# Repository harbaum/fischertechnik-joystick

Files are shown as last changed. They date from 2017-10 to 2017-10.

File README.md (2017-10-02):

# fischertechnik-joystick

This is a simple joystick interface for fischertechnik. It connects
to any PC and has ft compatible IOs for 8 fire buttons, four digital
direction buttons and four analog axes.

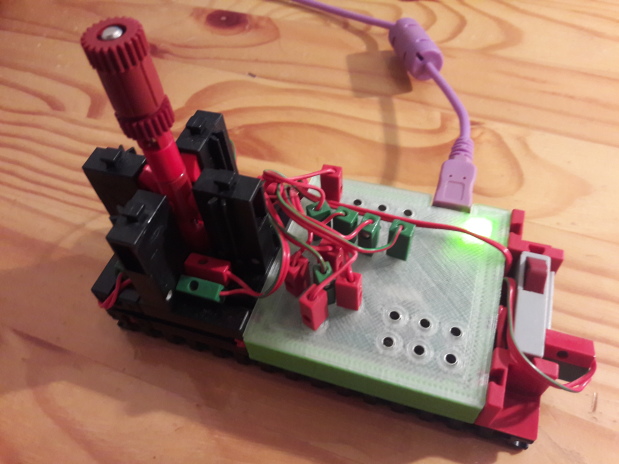
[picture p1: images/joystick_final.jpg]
 

This repository contains the schematic and the board layout in eagle format,
the firmware source code and a 3D printable case design.



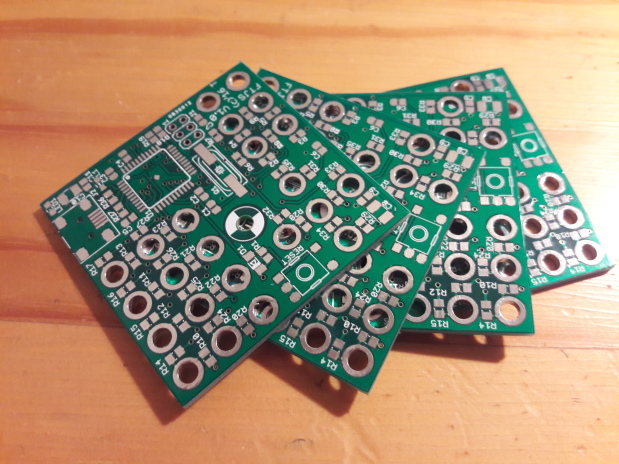
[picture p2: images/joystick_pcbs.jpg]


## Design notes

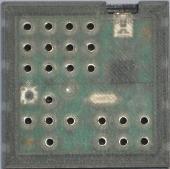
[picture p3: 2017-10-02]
images/prototype.jpg

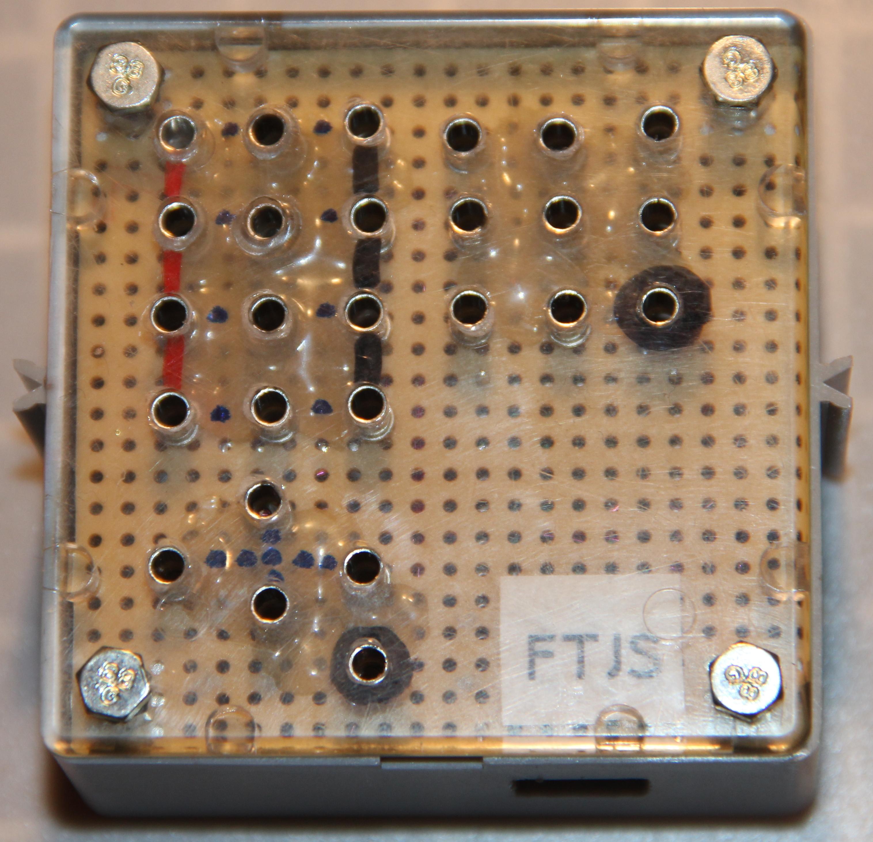
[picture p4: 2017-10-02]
images/modul.JPG

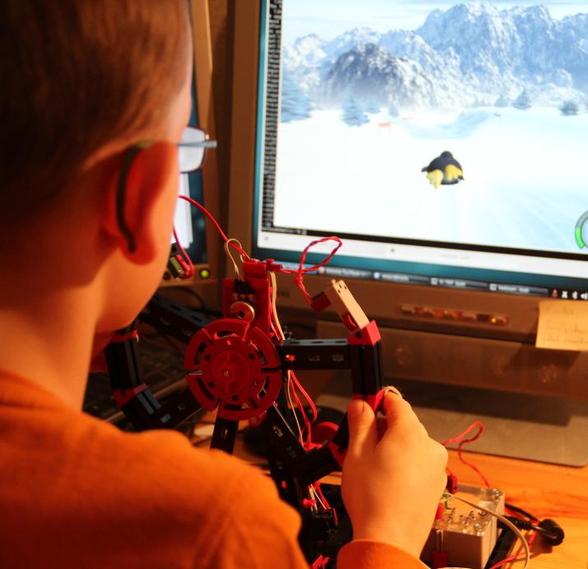
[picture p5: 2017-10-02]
images/ft_js.jpg

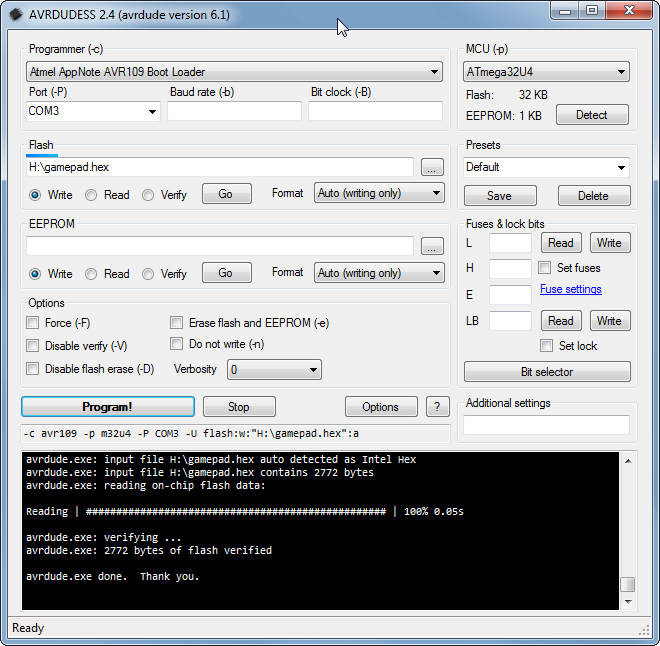
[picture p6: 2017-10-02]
images/avrdudess.png

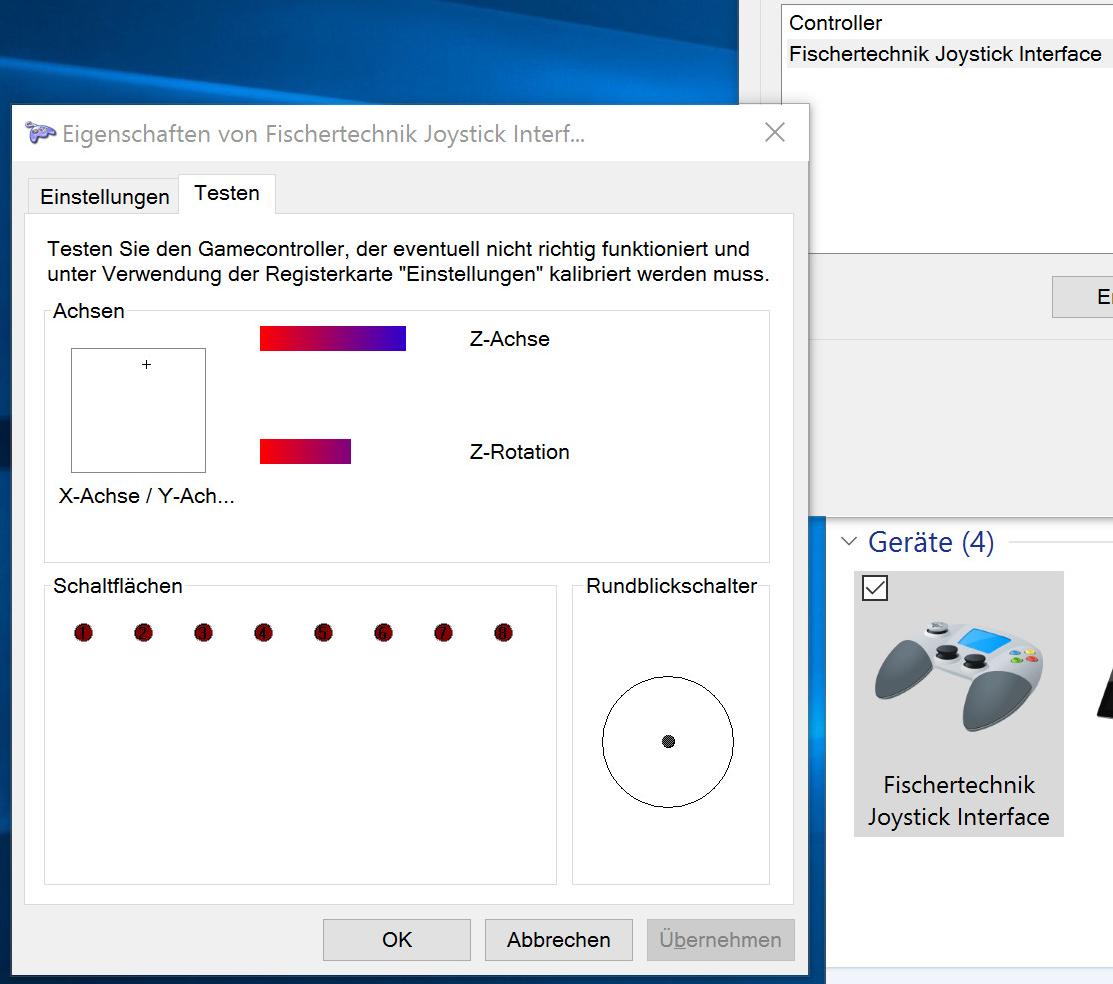
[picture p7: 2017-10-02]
images/win.jpg

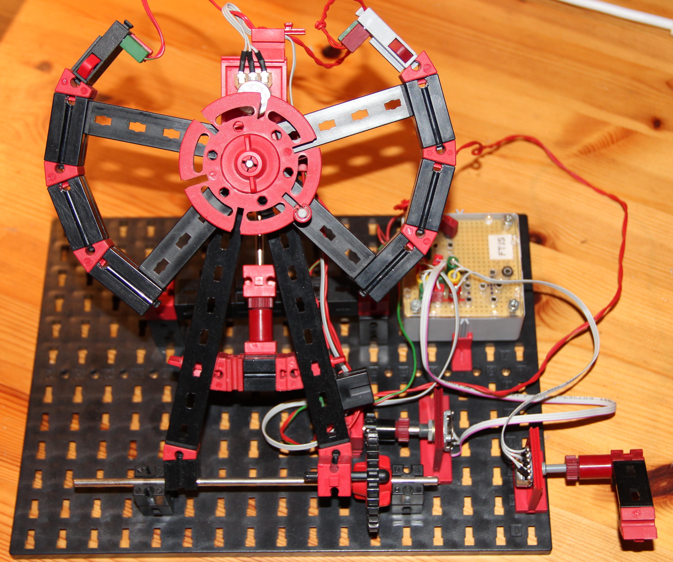
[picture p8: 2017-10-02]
images/lenkrad.JPG

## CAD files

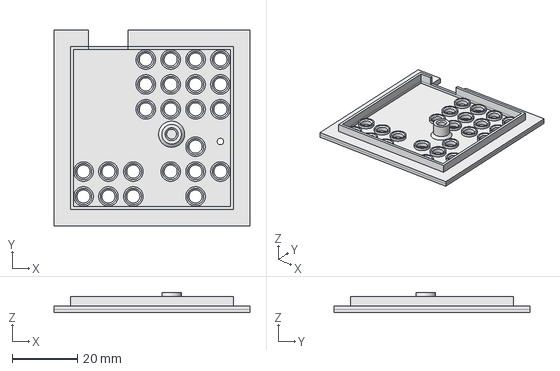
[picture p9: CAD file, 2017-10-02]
case/top.fcstd
60.0 x 60.0 x 6.20 mm

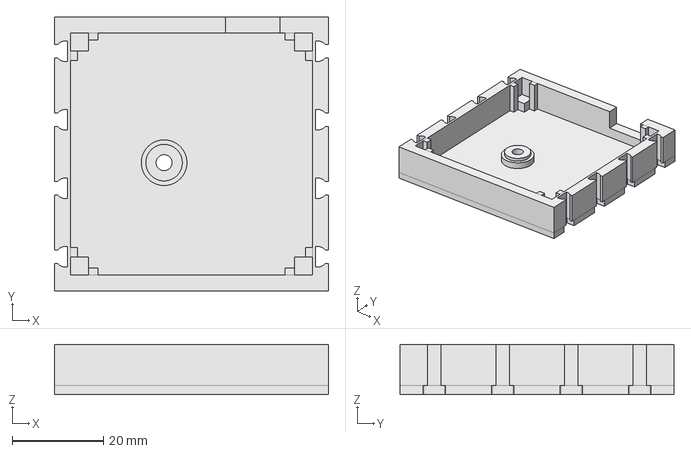
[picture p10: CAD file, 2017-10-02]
case/bottom.fcstd
60.0 x 60.0 x 11.0 mm

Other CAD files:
case/bottom.stl
case/top.stl

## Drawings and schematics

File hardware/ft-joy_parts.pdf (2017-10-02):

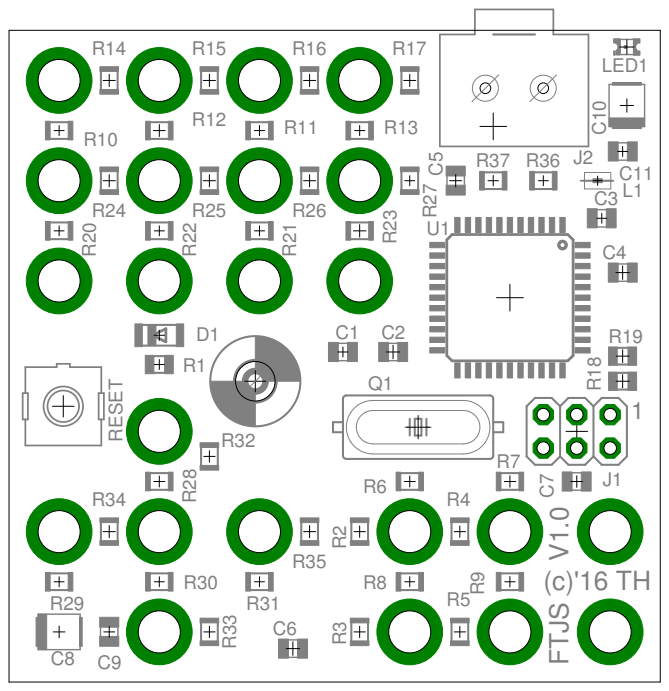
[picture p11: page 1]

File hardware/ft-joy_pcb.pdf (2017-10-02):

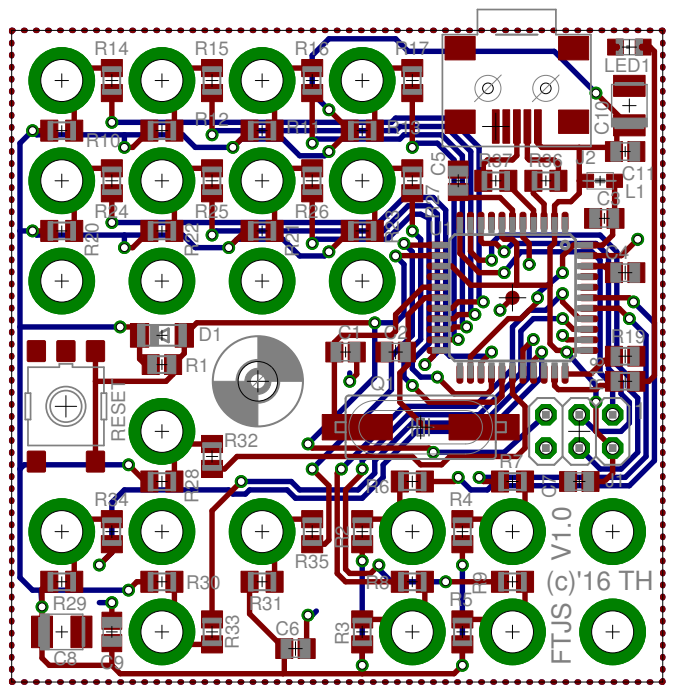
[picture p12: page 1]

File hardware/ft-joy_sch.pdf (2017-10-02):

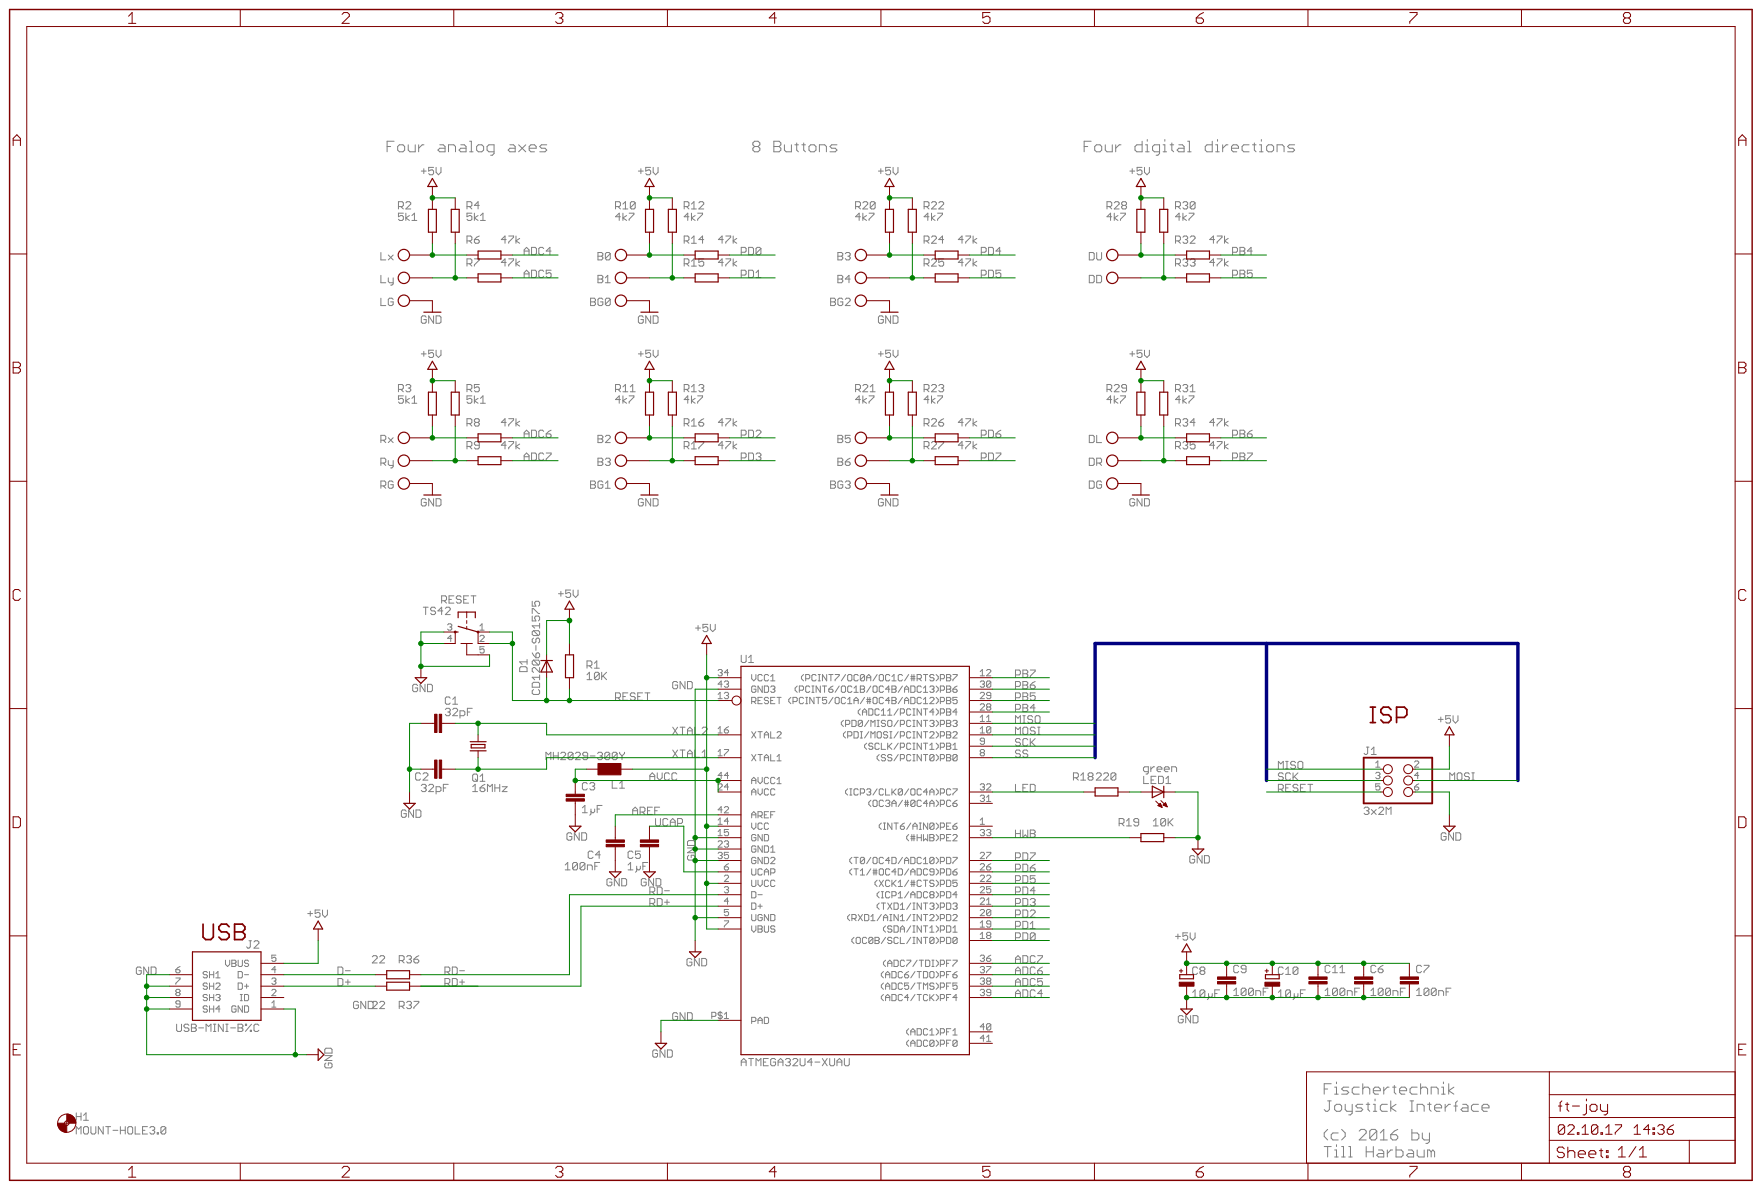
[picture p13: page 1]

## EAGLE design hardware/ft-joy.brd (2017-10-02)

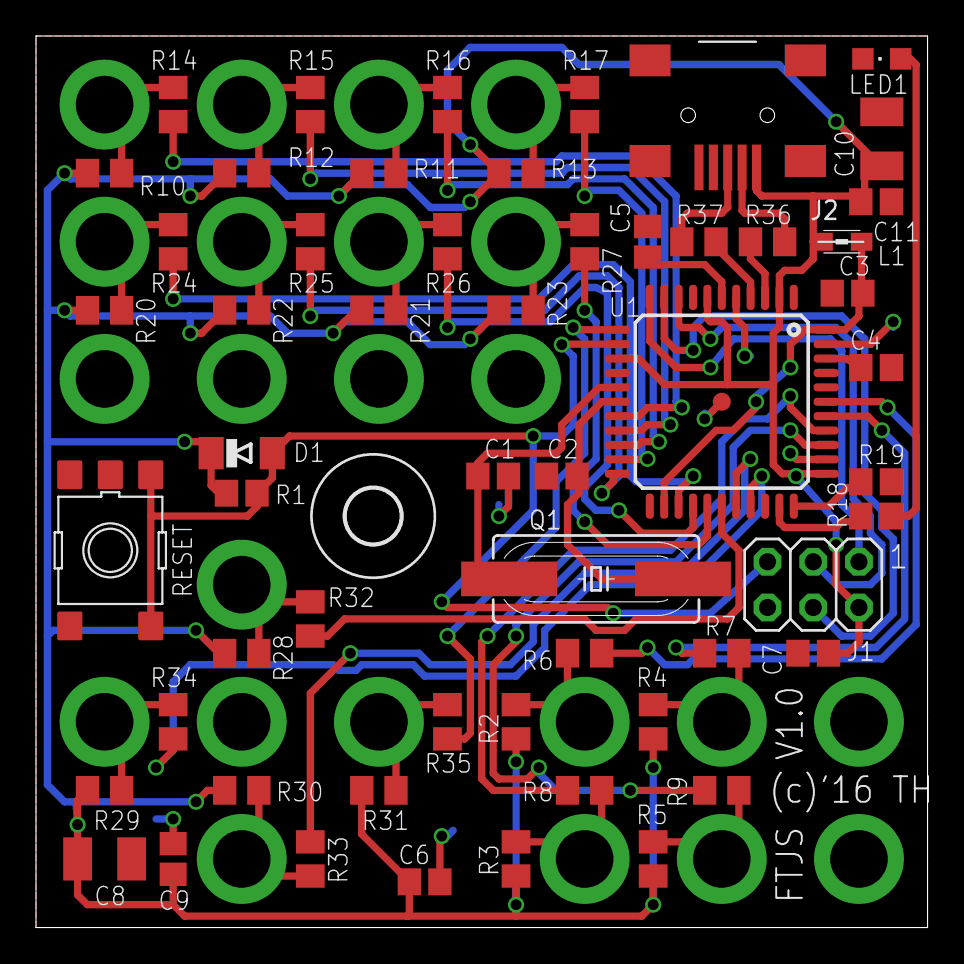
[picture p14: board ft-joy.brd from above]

Board: 2 copper layers, 49.5 x 49.5 mm, 80 parts (0 on the bottom side), 50 nets.

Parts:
C1, C2: 32pF; C0805
C3, C5: 1µF; C0805
C4, C6, C7, C9, C11: 100nF; C0805
C8, C10: 10µF; SMC_B
D1: CD1206-S01575; MINIMELF
H1: MOUNT-HOLE3.0; 3,0
J1: 3x2M; 2X03
J2: USB-MINI-B%C; USB-MINI-B_2
L1: MH2029-300Y; 0805
LED1: green; CHIPLED_0805
P1: Lx; FT-HUELSE
P2: Ly; FT-HUELSE
P3: LG; FT-HUELSE
P4: Rx; FT-HUELSE
P5: Ry; FT-HUELSE
P6: RG; FT-HUELSE
P7: B0; FT-HUELSE
P8: B1; FT-HUELSE
P9: BG0; FT-HUELSE
P10: B2; FT-HUELSE
P11, P13: B3; FT-HUELSE
P12: BG1; FT-HUELSE
P14: B4; FT-HUELSE
P15: BG2; FT-HUELSE
P16: B5; FT-HUELSE
P17: B6; FT-HUELSE
P18: BG3; FT-HUELSE
P19: DU; FT-HUELSE
P20: DD; FT-HUELSE
P21: DL; FT-HUELSE
P22: DR; FT-HUELSE
P23: DG; FT-HUELSE
Q1: 16MHz; HC49UP
R1, R19: 10K; R0805
R2, R3, R4, R5: 5k1; M0805
R6, R7, R8, R9, R14, R15, R16, R17, R24, R25, R26, R27, R32, R33, R34, R35: 47k; M0805
R10, R11, R12, R13, R20, R21, R22, R23, R28, R29, R30, R31: 4k7; M0805
R18: 220; R0805
R36, R37: 22; M0805
RESET: TS42
U1: ATMEGA32U4-XUAU; TQFP44-PAD

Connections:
+5V: C6.1, C7.1, C8.+, C9.1, C10.+, C11.1, D1.C, J1.2, J2.5, L1.1, R1.1, R2.1, R3.1, R4.1, R5.1, R10.1, R11.1, R12.1, R13.1, R20.1, R21.1, R22.1, R23.1, R28.1, R29.1, R30.1, R31.1, U1.2, U1.7, U1.14, U1.34
ADC4: R6.1, U1.39
ADC5: R7.1, U1.38
ADC6: R8.1, U1.37
ADC7: R9.1, U1.36
AREF: C4.1, U1.42
AVCC: C3.1, L1.2, U1.24, U1.44
D+: J2.3, R37.1
D-: J2.4, R36.1
GND: C1.1, C2.1, C3.2, C4.2, C5.2, C6.2, C7.2, C8.-, C9.2, C10.-, C11.2, J1.6, J2.1, J2.6, J2.7, J2.8, J2.9, LED1.C, P3.D1, P6.D1, P9.D1, P12.D1, P15.D1, P18.D1, P23.D1, R19.2, RESET.3, RESET.4, RESET.5, U1.5, U1.15, U1.23, U1.35, U1.43, U1.P$1
HWB: R19.1, U1.33
LED: R18.1, U1.32
MISO: J1.1, U1.11
MOSI: J1.4, U1.10
unnamed: P2.D1, R4.2, R7.2
unnamed: P4.D1, R3.2, R8.2
unnamed: P5.D1, R5.2, R9.2
unnamed: P7.D1, R10.2, R14.2
unnamed: P8.D1, R12.2, R15.2
unnamed: P10.D1, R11.2, R16.2
unnamed: LED1.A, R18.2
unnamed: P11.D1, R13.2, R17.2
unnamed: P13.D1, R20.2, R24.2
unnamed: P14.D1, R22.2, R25.2
unnamed: P16.D1, R21.2, R26.2
unnamed: P17.D1, R23.2, R27.2
unnamed: P19.D1, R28.2, R32.2
unnamed: P20.D1, R30.2, R33.2
unnamed: P21.D1, R29.2, R34.2
unnamed: P22.D1, R31.2, R35.2
unnamed: P1.D1, R2.2, R6.2
PB4: R32.1, U1.28
PB5: R33.1, U1.29
PB6: R34.1, U1.30
PB7: R35.1, U1.12
PD0: R14.1, U1.18
PD1: R15.1, U1.19
PD2: R16.1, U1.20
PD3: R17.1, U1.21
PD4: R24.1, U1.25
PD5: R25.1, U1.22
PD6: R26.1, U1.26
PD7: R27.1, U1.27
RD+: R37.2, U1.4
RD-: R36.2, U1.3
RESET: D1.A, J1.5, R1.2, RESET.1, RESET.2, U1.13
SCK: J1.3, U1.9
UCAP: C5.1, U1.6
XTAL1: C2.2, Q1.2, U1.17
XTAL2: C1.2, Q1.1, U1.16

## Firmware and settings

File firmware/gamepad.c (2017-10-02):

/* Fischertechnik Joystick Interface
 * Copyright (C) 2015 Till Harbaum
 */

#include <avr/io.h>
#include <util/delay.h>
#include <avr/interrupt.h>

#include "usb_gamepad.h"

#include "adctab.h"

#define LED_CONFIG	(DDRC |= (1<<7))
#define LED_OFF	        (PORTC &= ~(1<<7))
#define LED_ON	        (PORTC |= (1<<7))

#define CPU_PRESCALE(n)	(CLKPR = 0x80, CLKPR = (n))

void io_init() {
  // buttons
  DDRD  = 0x00; PORTD  = 0x00;   // Port D = Input, no pullups

  // direction
  DDRB &= 0x0f; PORTB &= 0x0f;   // Port B4-7 = Input, no pullups
}

#define GAMEPAD_BUT0         ((PIND & (1<<0))?0:0x01)  // Port D0
#define GAMEPAD_BUT1         ((PIND & (1<<1))?0:0x02)  // Port D1
#define GAMEPAD_BUT2         ((PIND & (1<<2))?0:0x04)  // Port D2
#define GAMEPAD_BUT3         ((PIND & (1<<3))?0:0x08)  // Port D3

#define GAMEPAD_BUT4         ((PIND & (1<<4))?0:0x10)  // Port D4
#define GAMEPAD_BUT5         ((PIND & (1<<5))?0:0x20)  // Port D5
#define GAMEPAD_BUT6         ((PIND & (1<<6))?0:0x40)  // Port D6
#define GAMEPAD_BUT7         ((PIND & (1<<7))?0:0x80)  // Port D7

#define GAMEPAD_LEFT_ON      ((PINB & (1<<6))?0:0x01)  // Port B6
#define GAMEPAD_RIGHT_ON     ((PINB & (1<<7))?0:0x01)  // Port B7
#define GAMEPAD_UP_ON        ((PINB & (1<<4))?0:0x01)  // Port B4
#define GAMEPAD_DOWN_ON      ((PINB & (1<<5))?0:0x01)  // Port B5

volatile uint8_t axis;
volatile uint16_t val[4];

/* adc interrupt service routine */
ISR(ADC_vect) {
  // read ADC value and store it
  if(axis < 4) 
    val[axis++] = ADC;

  // restart with next channel until all four channels
  // have been read
  if(axis < 4) {
    ADMUX = (ADMUX & ~((1<<MUX0) | (1<<MUX1)) ) | (axis << MUX0);
    _delay_us(10);
    ADCSRA |= (1<<ADSC);
  }
}

void adc_init() {
  /* 10 bit, AVcc reference */
  axis = 0;
  ADMUX = (1 << MUX2) | (0 << REFS1) | (1 << REFS0);

  /* conversion rate prescaler /64 */
  ADCSRA = (1<<ADEN) | (1<<ADIE) | (1<<ADPS1) | (1<<ADPS2);
  
  /* free running */
  ADCSRB = 0;
  
  /* start first conversion */
  ADCSRA |= (1<<ADSC);
}

int8_t adc_conv(uint16_t in) {
  // the useful input range only works in the lower 50% of the
  // adc range. The 32 values above the range return "max" 255, 
  // otherwise "out of range" 127. This makes sure that we can
  // handle potis which exceed the 4k7 limit a little bit but
  // can still detect open inputs correctly

  if(in > ADC_LIMIT) {
    if(in < ADC_LIMIT+32)
      return 255;
    else
      return 127;
  }

  return pgm_read_byte_near(adc2r + in);
}

int main(void) {
  // set for 16 MHz clock
  CPU_PRESCALE(0);
  
  LED_CONFIG;
  LED_OFF;

  usb_gamepad_reset_state();
    
  //  char i;  
  // for(i=0;i<10;i++)
    _delay_ms(10);
  
  // Initialize the USB, and then wait for the host to set configuration.
  // If the device is powered without a PC connected to the USB port,
  // this will wait forever.
  usb_init();
  while (!usb_configured()) /* wait */ ;
  
  // start adc conversion
  adc_init();
  io_init();
  
  LED_ON;    // everything is fine -> light led
  
  while (1) {
    // read gamepad data
    //    gamepad_read();

    // set "hat" values
    gamepad_state.direction = 8;
    if (GAMEPAD_UP_ON) {
      gamepad_state.direction = 0;
      if (GAMEPAD_LEFT_ON) {
	gamepad_state.direction = 7;
      } else if (GAMEPAD_RIGHT_ON) {
	gamepad_state.direction = 1;
      }
    } else {
      if (GAMEPAD_DOWN_ON) {
	gamepad_state.direction = 4;
	if (GAMEPAD_LEFT_ON) {
	  gamepad_state.direction = 5;
	} else if (GAMEPAD_RIGHT_ON) {
	  gamepad_state.direction = 3;
	}
      } else {
	if (GAMEPAD_LEFT_ON) {
	  gamepad_state.direction = 6;
	} else if (GAMEPAD_RIGHT_ON) {
	  gamepad_state.direction = 2;
	}
      }
    }

    // set button values
    gamepad_state.buttons =
      GAMEPAD_BUT0 | GAMEPAD_BUT1 |  GAMEPAD_BUT2 |  GAMEPAD_BUT3 | 
      GAMEPAD_BUT4 | GAMEPAD_BUT5 |  GAMEPAD_BUT6 |  GAMEPAD_BUT7;
    
    // wait for USB to become ready. This gives the ADC the time
    // to finish the conversion
    if(usb_gamepad_wait4tx() == 0) {

      if(axis == 4) {
	// set analogue axes values
	gamepad_state.l_x_axis = adc_conv(val[0]);
	gamepad_state.l_y_axis = adc_conv(val[1]);
	gamepad_state.r_x_axis = adc_conv(val[2]);
	gamepad_state.r_y_axis = adc_conv(val[3]);
      
	axis = 0;             // restart with axis 0 on channel 4
	ADMUX &= ~(3<<MUX0);  // restart with ADC input 4
	_delay_us(10);
	ADCSRA |= (1<<ADSC);  // start conversion
      }
	
      usb_gamepad_send();
    }
  }
}

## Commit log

2017-10-02 Initial release
    [bottom.fcstd, bottom.stl, ft-joy.brd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]
2017-10-02 Adjusted USB vid/pid

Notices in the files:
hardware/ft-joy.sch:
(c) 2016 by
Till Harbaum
